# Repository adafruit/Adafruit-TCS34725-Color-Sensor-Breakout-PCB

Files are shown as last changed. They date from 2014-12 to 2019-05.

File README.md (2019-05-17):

## Adafruit TCS34725 Color Sensor Breakout PCBs
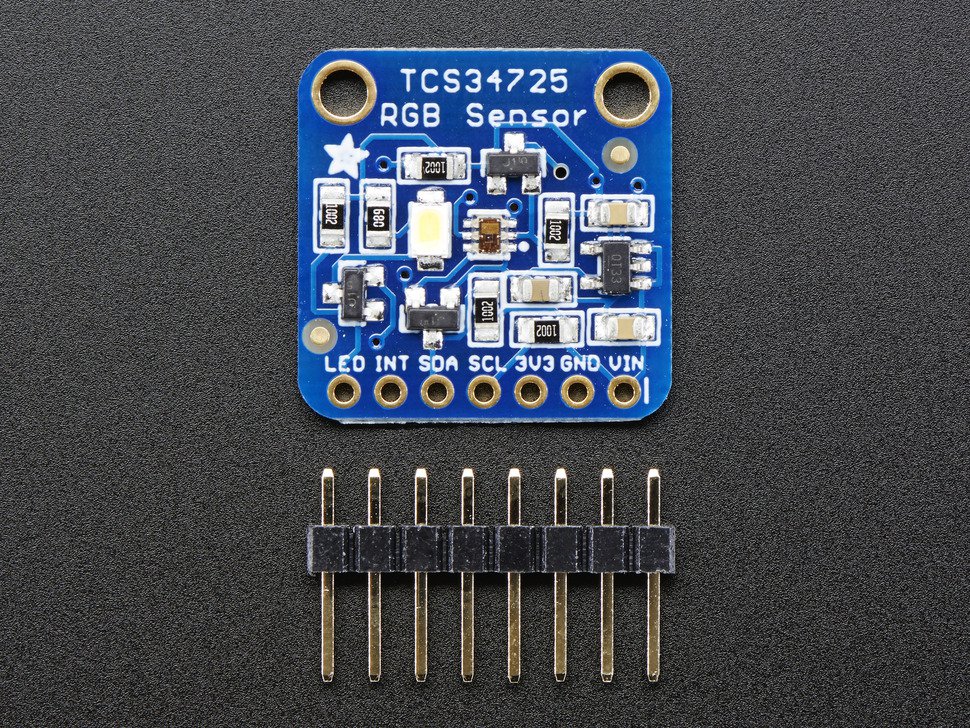
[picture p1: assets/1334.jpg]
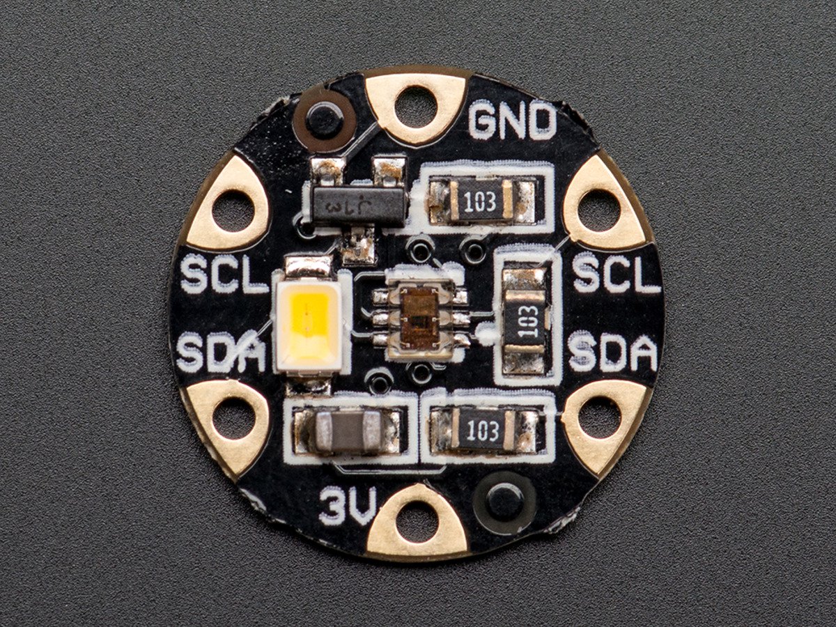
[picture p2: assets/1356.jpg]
&nbsp; <br />
Click to purchase from the Adafruit Shop:
- [RGB Color Sensor](https://www.adafruit.com/product/1334)
- [Flora Color Sensor](https://www.adafruit.com/product/1356)

We found the best color sensor on the market, the TCS34725, which has RGB and Clear light sensing elements. An IR blocking filter, integrated on-chip and localized to the color sensing photodiodes, minimizes the IR spectral component of the incoming light and allows color measurements to be made accurately. The filter means you'll get much truer color than most sensors, since humans don't see IR. The sensor also has an incredible 3,800,000:1 dynamic range with adjustable integration time and gain so it is suited for use behind darkened glass.

PCB files for the Adafruit TCS34725 Color Sensor Breakouts - 
Format is EagleCAD schematic and board layout

### License

Adafruit invests time and resources providing this open source design, please support Adafruit and open-source hardware by purchasing products from [Adafruit](https://www.adafruit.com)!

All text above must be included in any redistribution

Designed by Limor Fried/Ladyada for Adafruit Industries.
Creative Commons Attribution/Share-Alike, all text above must be included in any redistribution. 
See license.txt for additional information.

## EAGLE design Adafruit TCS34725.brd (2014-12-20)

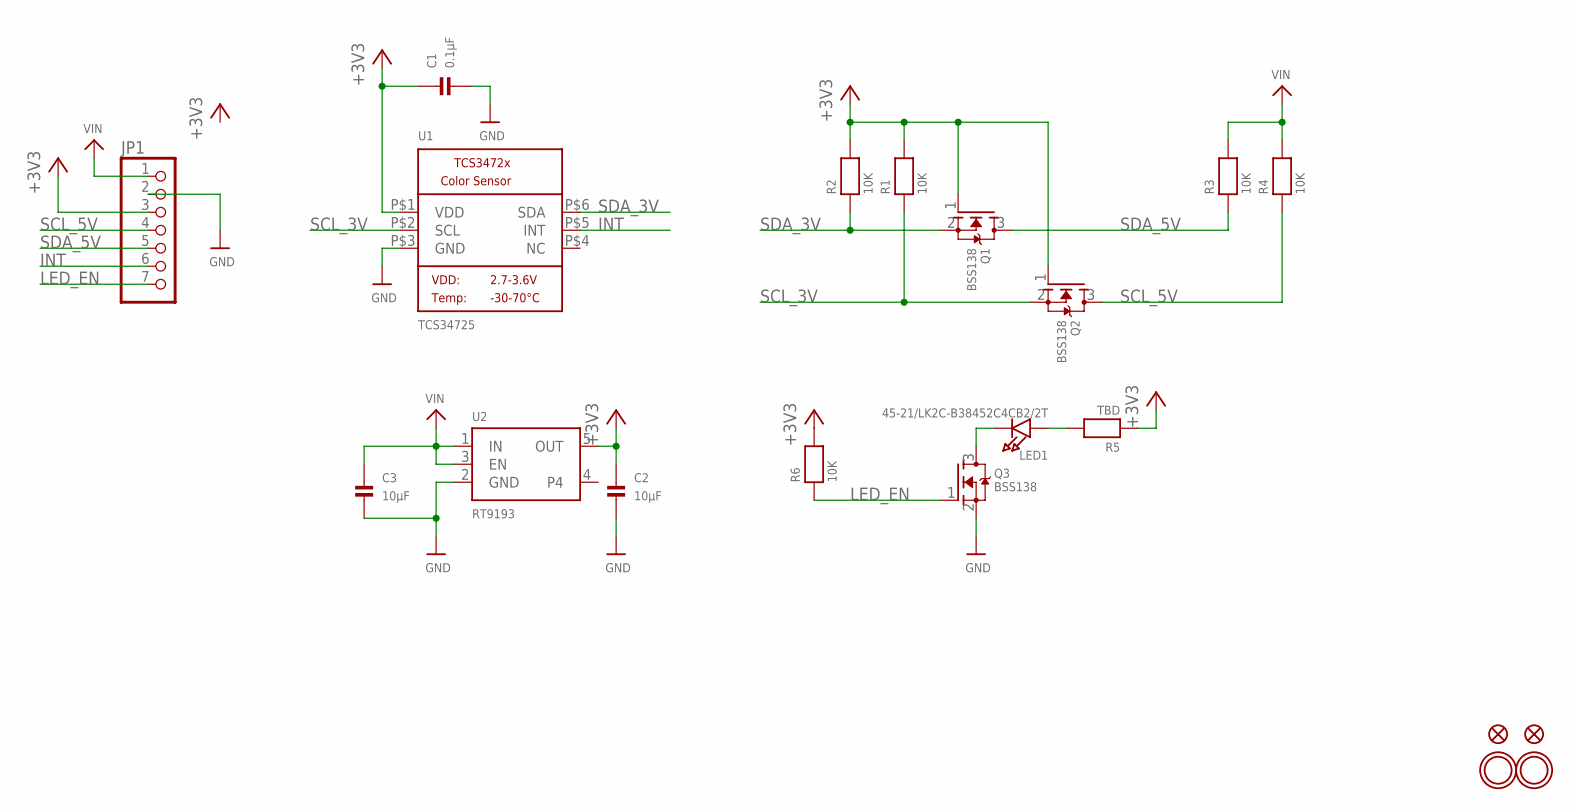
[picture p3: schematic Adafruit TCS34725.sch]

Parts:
C1: 0.1µF; _0805
C2, C3: 10µF; _0805
FID1, FID2: FIDUCIAL""; FIDUCIAL_1MM
JP1: HEADER-1X770MIL; 1X07_ROUND_70
LED1: 45-21/LK2C-B38452C4CB2/2T; EVERLIGHT_45-21
Q1, Q2, Q3: BSS138; SOT23-WIDE
R1, R2, R3, R4, R6: 10K; _0805
R5: TBD; _0805
U1: TCS34725; TCS3472_FN6
U2: RT9193; SOT23-5
U$8, U$14: MOUNTINGHOLE2.5; MOUNTINGHOLE_2.5_PLATED

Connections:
+3V3: C1.1, C2.1, JP1.3, Q1.1 (G), Q2.1 (G), R1.2, R2.2, R5.1, R6.2, U1.P$1 (VDD), U2.5 (OUT)
GND: C1.2, C2.2, C3.2, JP1.2, Q3.2 (S), U1.P$3 (GND), U2.2 (GND)
INT: JP1.6, U1.P$5 (INT)
LED_EN: JP1.7, Q3.1 (G), R6.1
unnamed: LED1.K (C), Q3.3 (D)
unnamed: LED1.A, R5.2
SCL_3V: Q2.2 (S), R1.1, U1.P$2 (SCL)
SCL_5V: JP1.4, Q2.3 (D), R4.1
SDA_3V: Q1.2 (S), R2.1, U1.P$6 (SDA)
SDA_5V: JP1.5, Q1.3 (D), R3.1
VIN: C3.1, JP1.1, R3.2, R4.2, U2.1 (IN), U2.3 (EN)

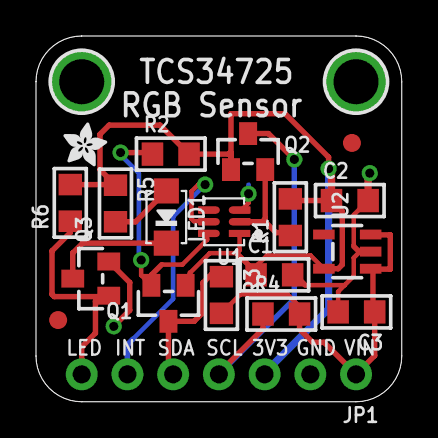
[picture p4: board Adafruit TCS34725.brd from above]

Board: 2 copper layers, 20.3 x 20.3 mm, 22 parts (1 on the bottom side), 11 nets.

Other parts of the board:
U$2: ADAFRUIT_2.5MM
U$18: ADAFRUIT_5MM

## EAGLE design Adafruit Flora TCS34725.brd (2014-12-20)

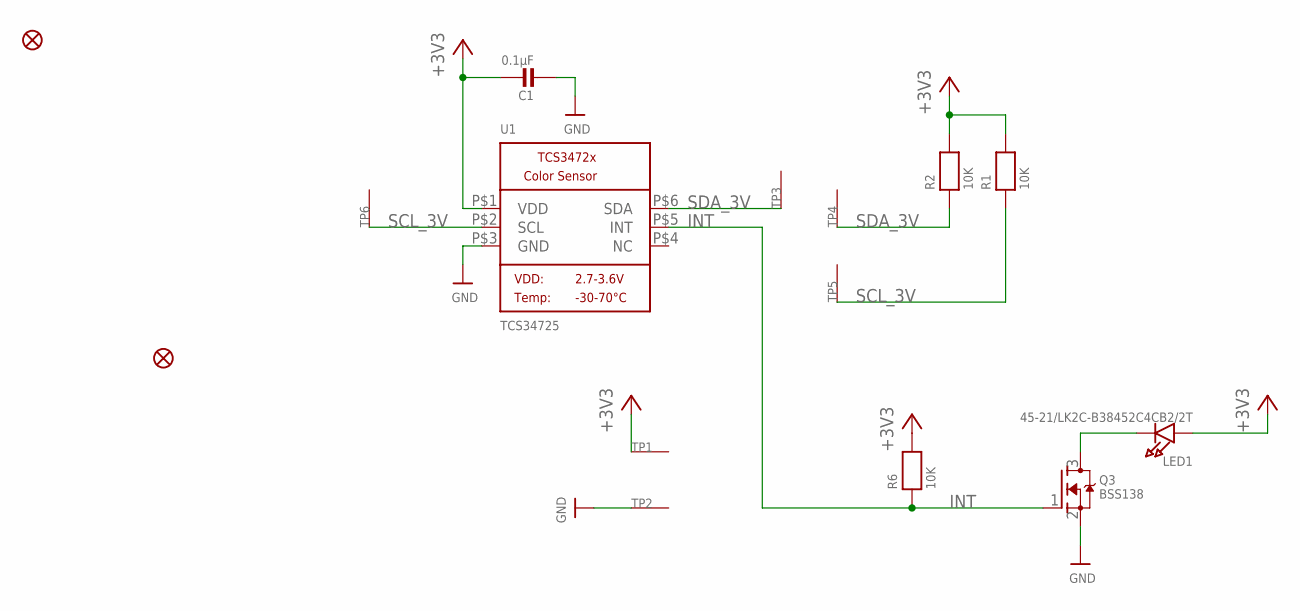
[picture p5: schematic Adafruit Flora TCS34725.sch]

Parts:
C1: 0.1µF; _0805
FID1, FID2: FIDUCIAL""; FIDUCIAL_1MM
LED1: 45-21/LK2C-B38452C4CB2/2T; EVERLIGHT_45-21
Q3: BSS138; SOT23-WIDE
R1, R2, R6: 10K; _0805
TP1, TP2, TP3, TP4, TP5, TP6: SEWTAP0.5IN; SEWINGTAP_0.5
U1: TCS34725; TCS3472_FN6

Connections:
+3V3: C1.1, LED1.A, R1.2, R2.2, R6.2, TP1.TAP, U1.P$1 (VDD)
GND: C1.2, Q3.2 (S), TP2.TAP, U1.P$3 (GND)
INT: Q3.1 (G), R6.1, U1.P$5 (INT)
unnamed: LED1.K (C), Q3.3 (D)
SCL_3V: R1.1, TP5.TAP, TP6.TAP, U1.P$2 (SCL)
SDA_3V: R2.1, TP3.TAP, TP4.TAP, U1.P$6 (SDA)

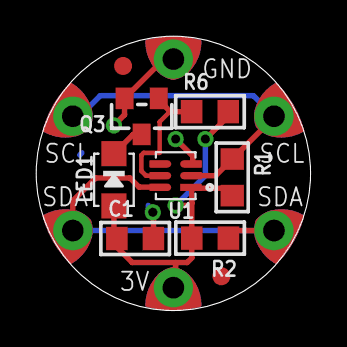
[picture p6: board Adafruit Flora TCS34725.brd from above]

Board: 2 copper layers, 15.2 x 15.2 mm, 16 parts (1 on the bottom side), 6 nets.

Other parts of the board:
U$8: ADAFRUIT_3.5MM

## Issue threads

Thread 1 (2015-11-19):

Color issue with the TDS34725

AxelGalliot, 2015-11-19:
Hello, I have a color issue with the TCS34725. I used the code given with it :

<code>#include <Wire.h>
#include "Adafruit_TCS34725.h"

/* Example code for the Adafruit TCS34725 breakout library */

/* Connect SCL    to analog 5
   Connect SDA    to analog 4
   Connect VDD    to 3.3V DC
   Connect GROUND to common ground */

/* Initialise with default values (int time = 2.4ms, gain = 1x) */
// Adafruit_TCS34725 tcs = Adafruit_TCS34725();

/* Initialise with specific int time and gain values */
Adafruit_TCS34725 tcs = Adafruit_TCS34725(TCS34725_INTEGRATIONTIME_700MS, TCS34725_GAIN_1X);

void setup(void) {
  Serial.begin(9600);

  if (tcs.begin()) {
    Serial.println("Found sensor");
  } else {
    Serial.println("No TCS34725 found ... check your connections");
    while (1);
  }

  // Now we're ready to get readings!
}

void loop(void) {
  uint16_t r, g, b, c, colorTemp, lux;
  int Teinte;
  String Couleur;
  tcs.getRawData(&r, &g, &b, &c);
  colorTemp = tcs.calculateColorTemperature(r, g, b);
  lux = tcs.calculateLux(r, g, b);

  Teinte=getTeinte(r, g, b);
  Serial.print("H : "); Serial.print(Teinte, DEC); Serial.print(" ");
  Serial.println("");
  AfficheCouleur(Teinte);

  /*Serial.print("Color Temp: "); Serial.print(colorTemp, DEC); Serial.print(" K - ");
  Serial.print("Lux: "); Serial.print(lux, DEC); Serial.print(" - ");
  Serial.print("R: "); Serial.print(r, DEC); Serial.print(" ");
  Serial.print("G: "); Serial.print(g, DEC); Serial.print(" ");
  Serial.print("B: "); Serial.print(b, DEC); Serial.print(" ");
  Serial.print("C: "); Serial.print(c, DEC); Serial.print(" ");
  Serial.print("Teinte: "); Serial.print(Teinte, DEC); Serial.print(" ");
  Serial.println(" ");*/
  delay(5000);
}

float getTeinte(uint16_t pr, uint16_t pg, uint16_t pb)
{
  int H;
  float r= (float)pr/255;
  float g= (float)pg/255;
  float b= (float)pb/255;
  float Cmax = Max(r, g, b);

  Serial.print("r: "); Serial.print(r,2); Serial.print(" ");
  Serial.print("g: "); Serial.print(g,2); Serial.print(" ");
  Serial.print("b: "); Serial.print(b,2); Serial.print(" ");
  Serial.print("Cmax: "); Serial.print(Cmax,2); Serial.print(" ");
  float Cmin = Min(r, g, b);
  Serial.print("Cmin: "); Serial.print(Cmin,2); Serial.print(" ");
  float Delta = Cmax - Cmin;
  Serial.print("Delta: "); Serial.print(Delta,2); Serial.print(" ");
  Serial.println("");

  H= getH(r, g, b, Cmax, Delta);
  return H;
}

float Min(float pr, float pg, float pb)
{
  if(pr<pg && pr<pb)
    return pr ;
  else if(pg<pb && pg<pr)
    return pg ;
  else
    return pb ;
}

float Max(float pr, float pg, float pb)
{
  if(pr>pg && pr>pb)
    return pr ;
  else if(pg>pb && pg>pr)
    return pg ;
  else
    return pb ;
}

int getH(float pr, float pg, float pb, float pCmax, float pDelta)
{
  int Temp;
  if(pDelta==0)
    return 0;
  else if(pCmax==pr)
  {
    Temp= 60*((pg-pb)/pDelta);
    Temp= Temp%6;
  }
  else if(pCmax==pg)
    Temp= 60*(((pb-pr)/pDelta)+2);
  else
    Temp= 60*(((pr-pg)/pDelta)+4);
  return Temp;
}

void AfficheCouleur(int pH)
{
  String Couleur;
  if( (pH<=15 && pH>=0))
    Serial.print("Couleur: Rouge ");
  else if(pH<=45 && pH>15)
    Serial.print("Couleur: Orange ");
  else if(pH<=75 && pH>45)
    Serial.print("Couleur: Jaune ");
  else if(pH<=135 && pH>75)
    Serial.print("Couleur: Vert ");
  if(pH<=255 && pH>135)
    Serial.print("Couleur: Bleu ");
  else if(pH<=345 && pH>255|| pH>345)
    Serial.print("Couleur: Violet ");
  Serial.println("");
  Serial.println("");
}</code>

But the pH is always below what it need to be, if I put yellow on the captor, the pH will be between 1 and 5. If I put black, the pH is green. I have this problem on 2 drivers.

ladyada, 2015-11-19:
hiya for tech support for adafruit products, post to forums.adafruit.com - we dont do tech support in github :)

Closed 2015-11-19.

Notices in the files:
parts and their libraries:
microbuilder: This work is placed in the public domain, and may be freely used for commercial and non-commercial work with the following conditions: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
